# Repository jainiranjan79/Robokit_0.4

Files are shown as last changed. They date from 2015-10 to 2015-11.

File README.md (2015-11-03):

# scratchduino-RoboKit v0.4
This repository includes **body, schematics, PCB, documentation and sources** for RoboKit v0.4

#Directories
* Body - *the body of roboplatform and sensors*
* Documentation - *the .pdf schematics, etc*
* Firmware - *the firmware for RoboKit v0.4*
* PCB - *Printed Circuit Boards for Roboplatform and sensors*
    * Gerber - *gerber files + gerber drill files*
        * Cartridge
        * ...
    * SVG - *svg files without drill files*
        * Cartridge
        * ...
* Sources - *the sources for PCB and Body*
    * Cartridge - *Kicad files for PCB*
        * make - *This bash script distribute Gerber, SVG and PDF files to directories PCB,Documentation*
        * PCB - *Here you need print PCB in svg and gerber formats( read make )*
    * ...

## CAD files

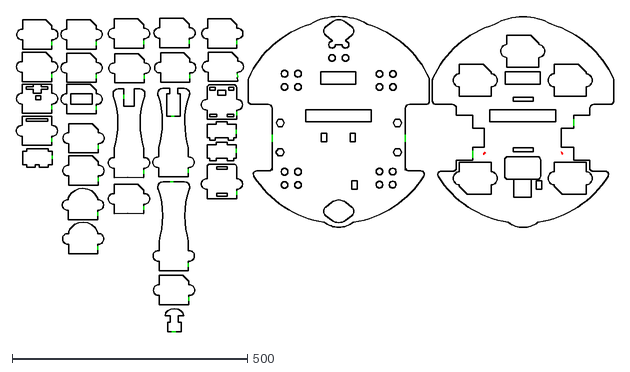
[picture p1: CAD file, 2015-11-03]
Body/2mm.dxf
1270.6 x 670.4

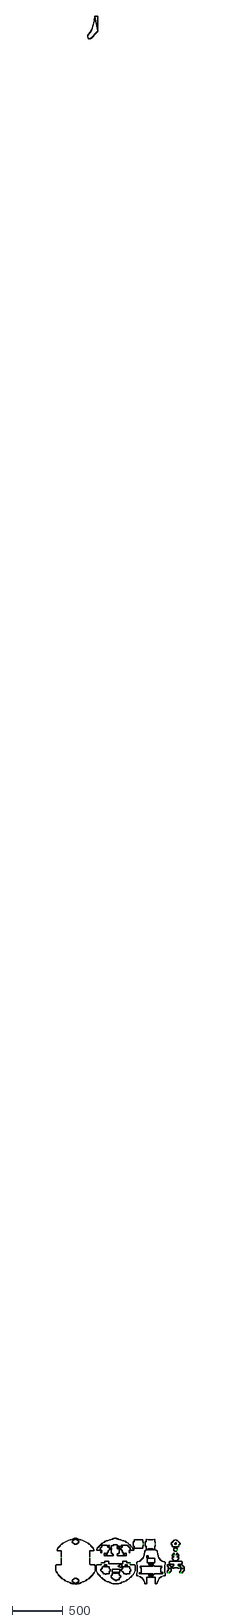
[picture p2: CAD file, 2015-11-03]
Body/3mm.dxf
1260.2 x 15413.3

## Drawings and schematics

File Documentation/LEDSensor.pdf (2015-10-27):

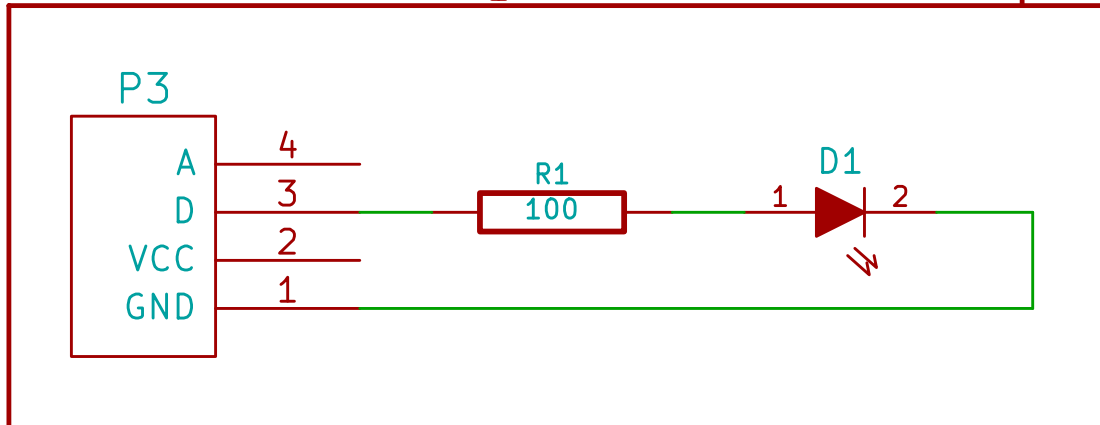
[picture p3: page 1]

Id: 1/1 Title: noname.sch File: LEDSensor.sch
Sheet: /

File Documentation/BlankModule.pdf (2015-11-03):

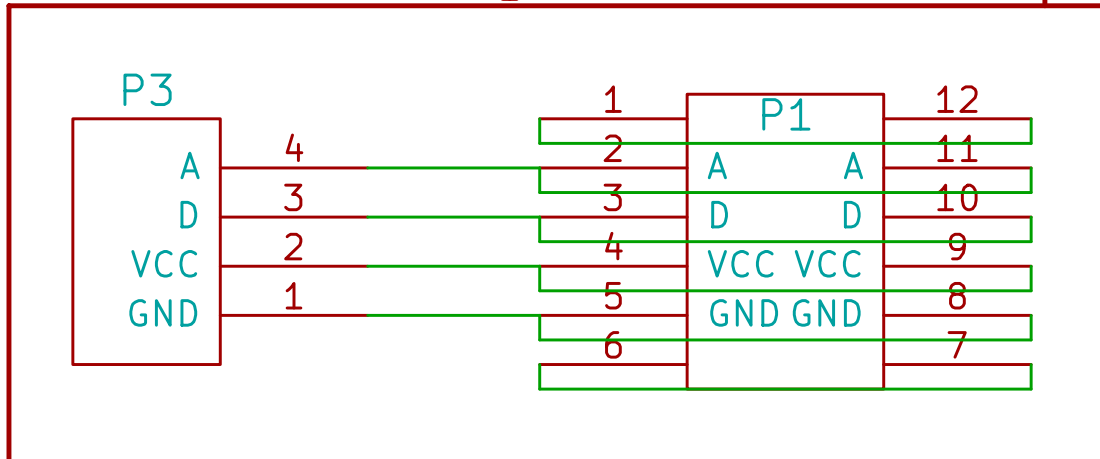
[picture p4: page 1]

Id: 1/1 Title: noname.sch File: BlankModule.sch Sheet: /

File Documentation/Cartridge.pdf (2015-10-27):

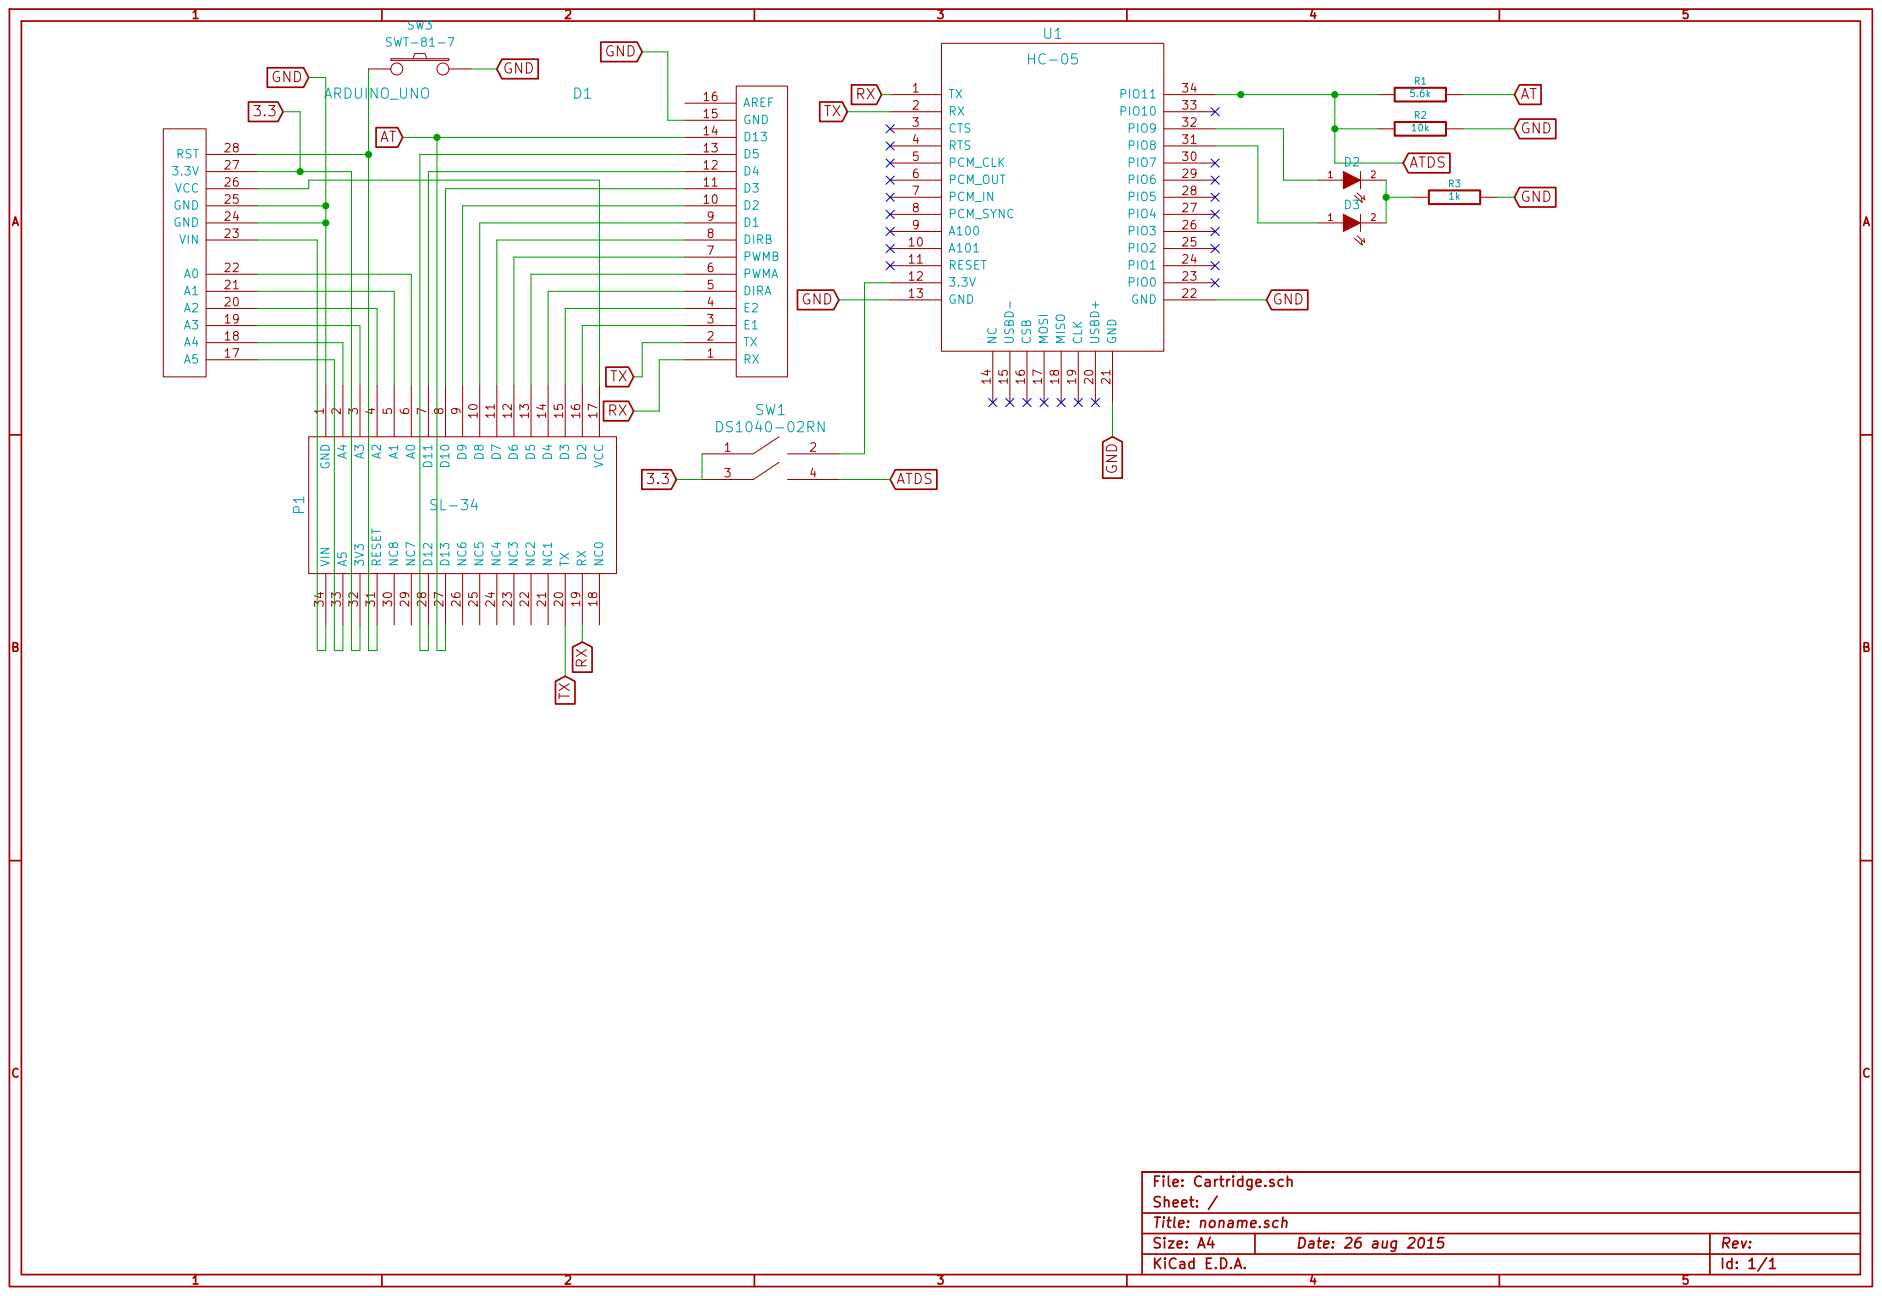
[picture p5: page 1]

9 D8 10 TX 20 NC8 30 D7 11 NC1 21 RESET 31 D6 12 NC2 22 3V3 32 D5 13 NC3 23 A5 33 D4 14 NC4 24 VIN 34 D3 15 NC5 25 D2 16 NC6 26 VCC 17 D13 27 NC0 18 D12 28 RX 19 NC7 29 P1SL-34

Id: 1/1 Title: noname.sch File: Cartridge.sch

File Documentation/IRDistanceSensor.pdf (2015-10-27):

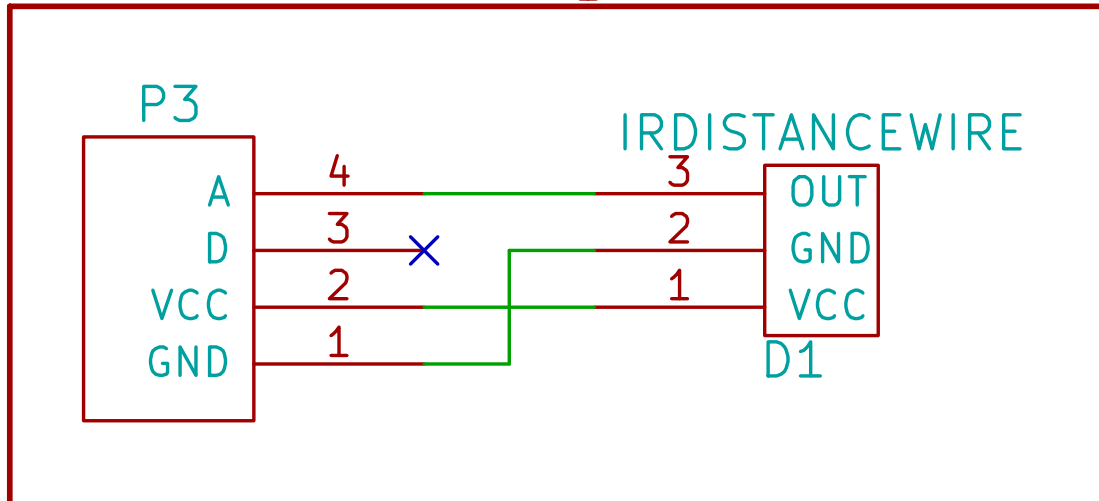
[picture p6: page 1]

Id: 1/1 Title: noname.sch File: IRDistanceSensor.sch
Sheet: /

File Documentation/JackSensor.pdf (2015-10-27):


Id: 1/1 Title: noname.sch File: JackSensor.sch
Sheet: /

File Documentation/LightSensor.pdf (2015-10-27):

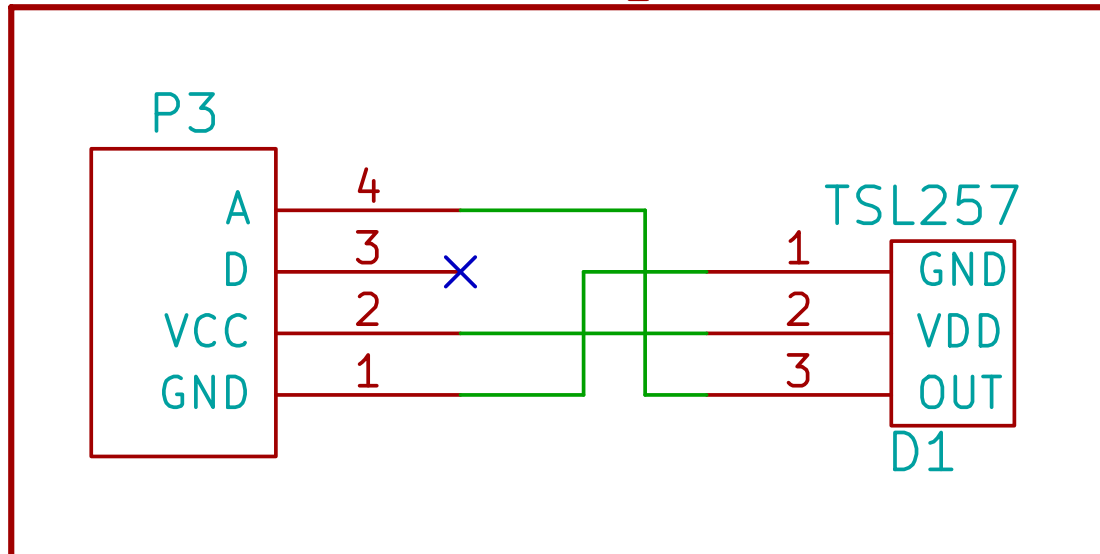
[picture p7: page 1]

Id: 1/1 Title: noname.sch File: LightSensor.sch
Sheet: /

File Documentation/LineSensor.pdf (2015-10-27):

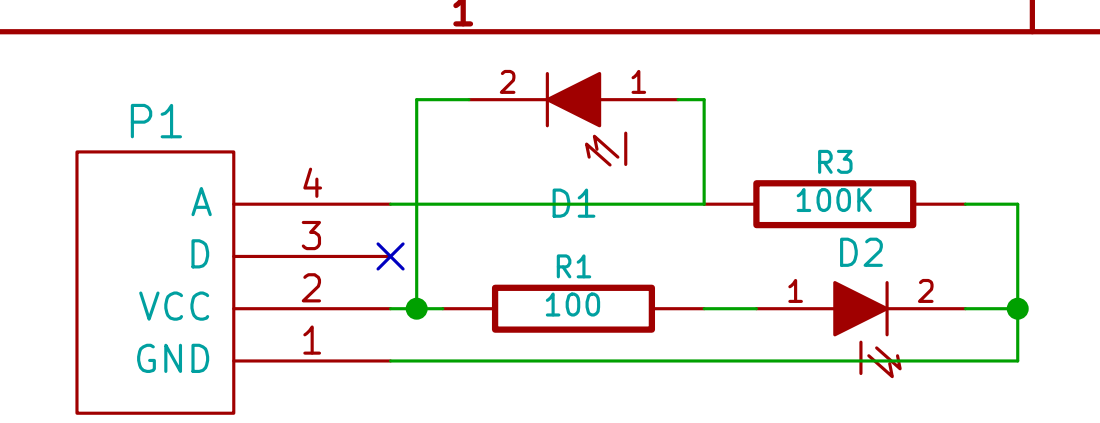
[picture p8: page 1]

Id: 1/1 Title: noname.sch File: LineSensor.sch
Sheet: /

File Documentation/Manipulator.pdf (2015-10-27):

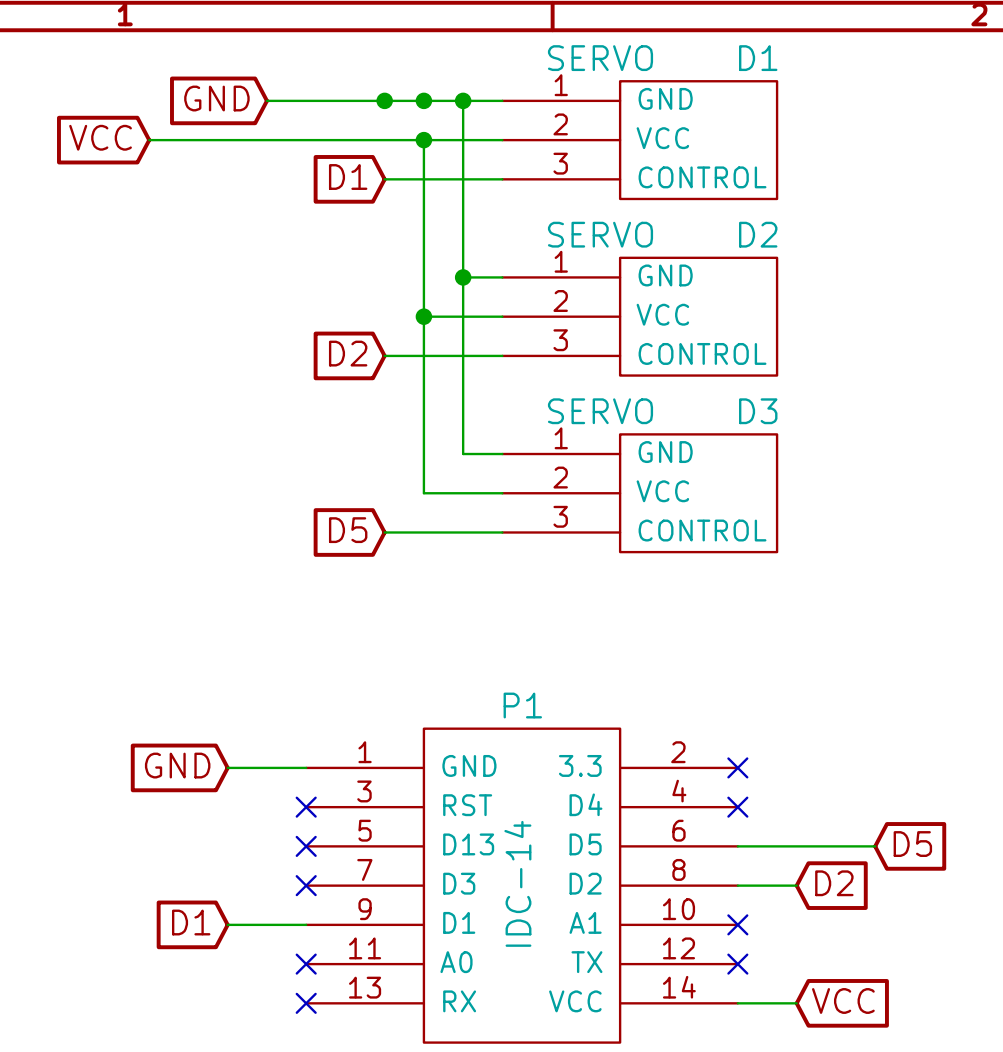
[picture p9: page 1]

Id: 1/1 Title: File: Manipulator.sch
Sheet: /

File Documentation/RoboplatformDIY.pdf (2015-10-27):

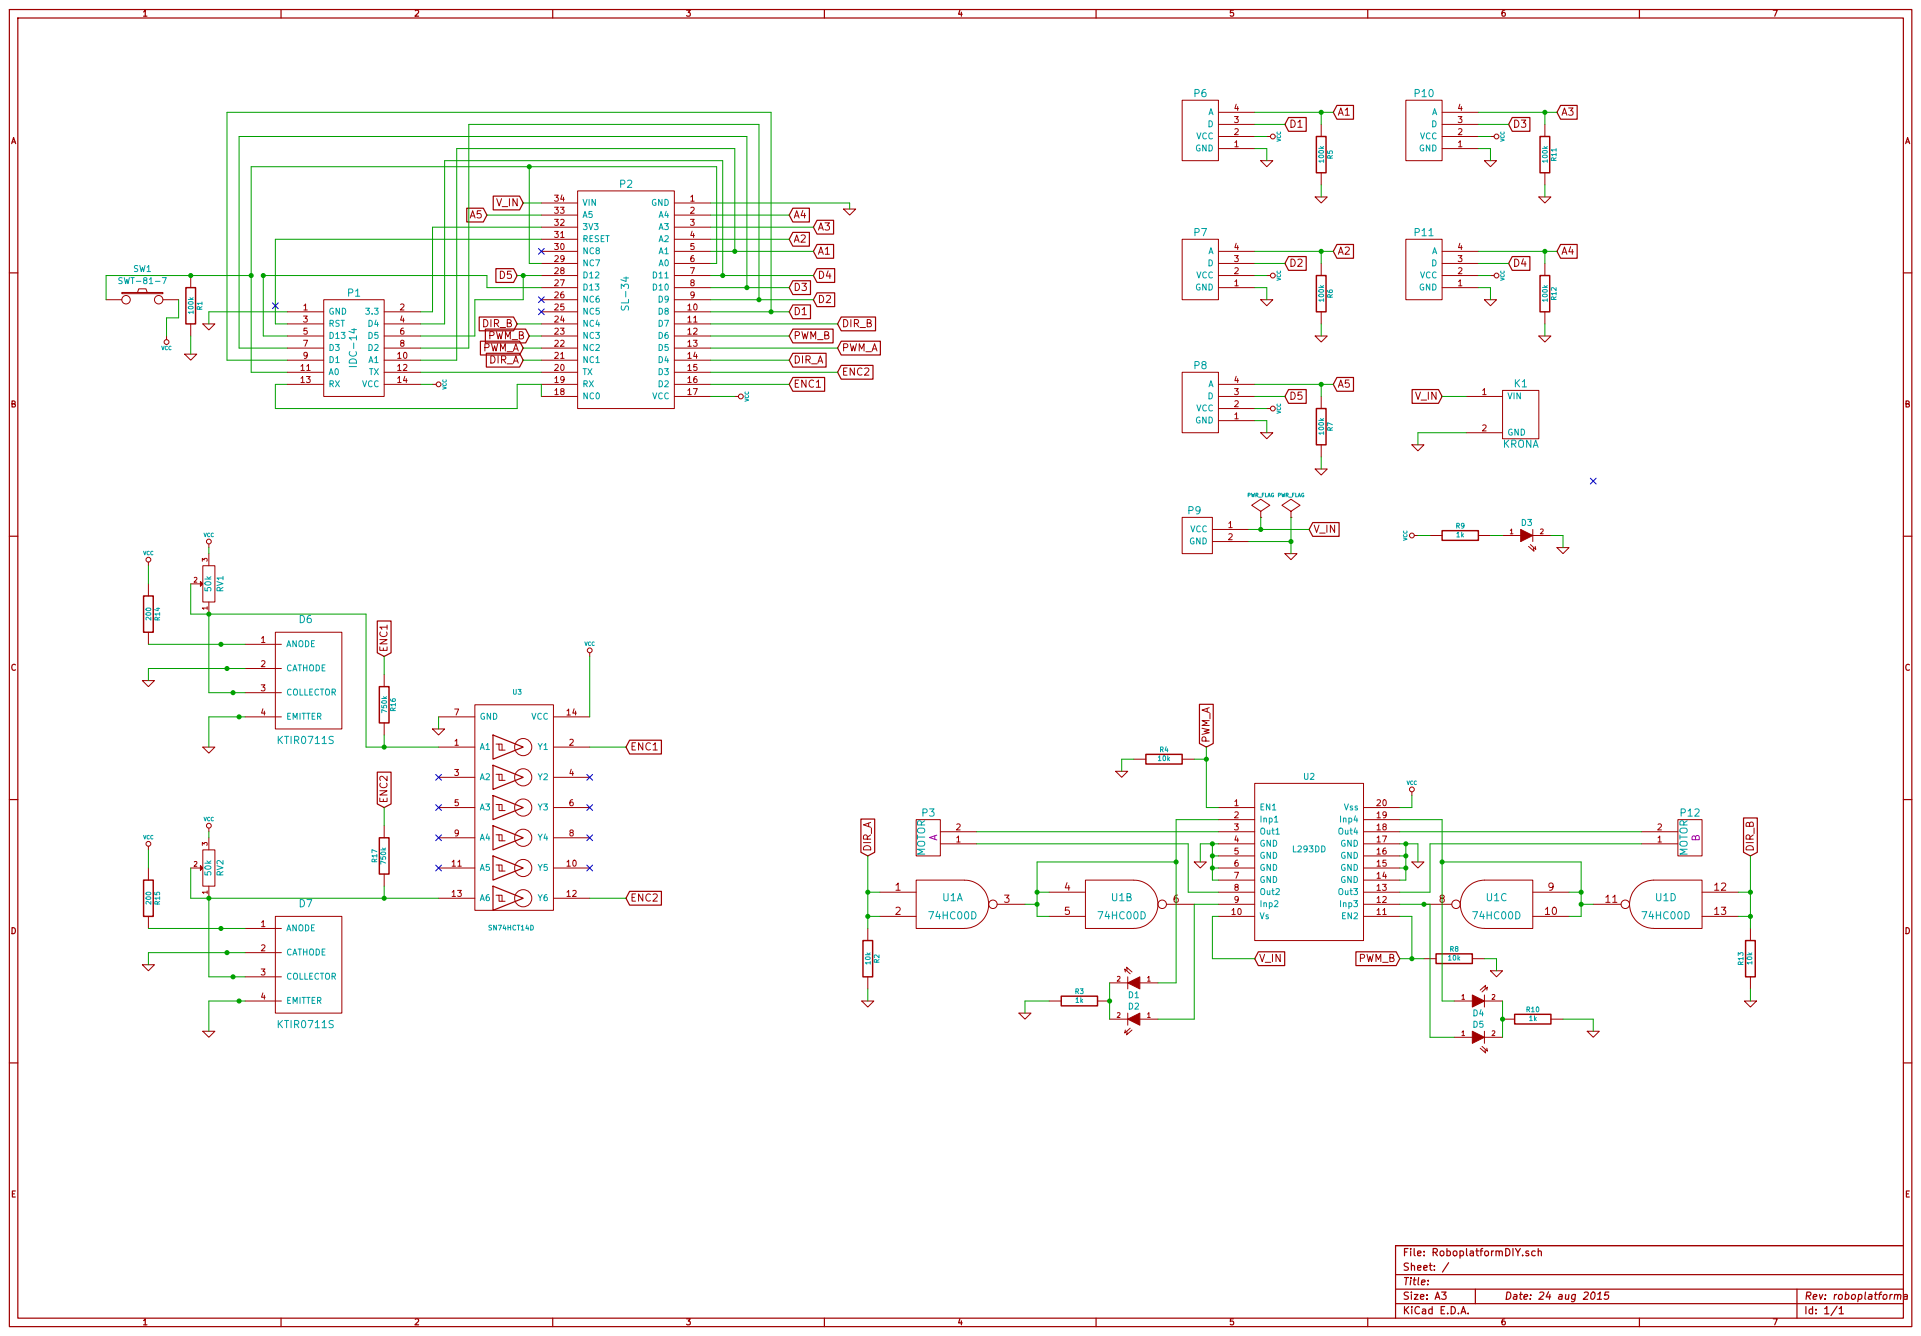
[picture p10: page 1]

Id: 1/1 Title: File: RoboplatformDIY.sch

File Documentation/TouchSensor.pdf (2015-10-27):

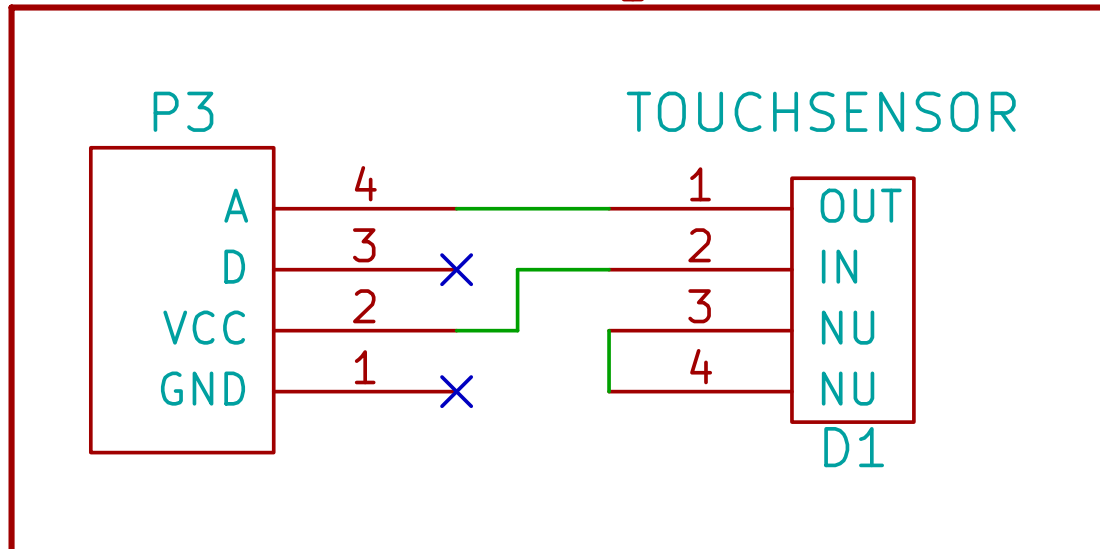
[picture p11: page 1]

Id: 1/1 Title: noname.sch File: TouchSensor.sch
Sheet: /

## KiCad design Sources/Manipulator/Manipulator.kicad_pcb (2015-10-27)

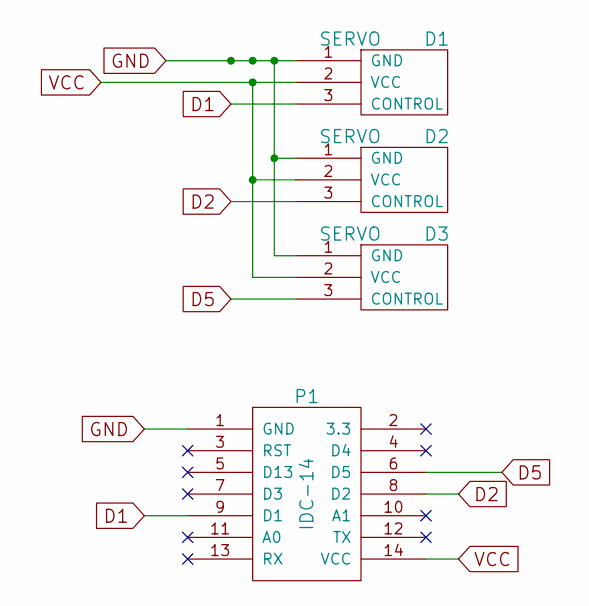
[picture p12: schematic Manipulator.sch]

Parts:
D1, D2, D3: SERVO
P1: IDC-14

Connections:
D1: D1.3 (CONTROL), P1.9 (D1)
D2: D2.3 (CONTROL), P1.8 (D2)
D5: D3.3 (CONTROL), P1.6 (D5)
GND: D1.1 (GND), D2.1 (GND), D3.1 (GND), P1.1 (GND)
VCC: D1.2 (VCC), D2.2 (VCC), D3.2 (VCC), P1.14 (VCC)

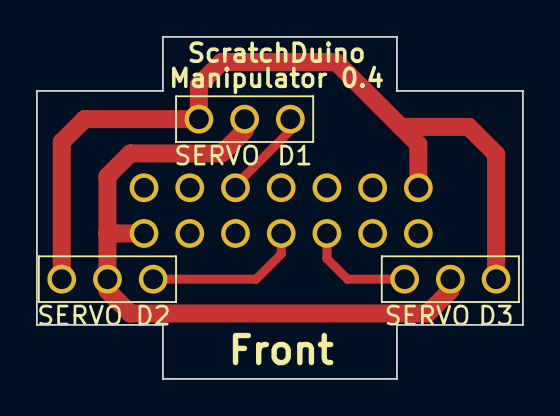
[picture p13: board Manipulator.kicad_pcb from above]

Board: 2 copper layers, 27.0 x 19.0 mm, 4 parts (1 on the bottom side), 5 nets.

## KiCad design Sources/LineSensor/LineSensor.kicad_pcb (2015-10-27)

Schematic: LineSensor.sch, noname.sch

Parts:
D1: INFAREDPHOTODIODE
D2: INFAREDLED
P1: SENSOR
R1: 100
R3: 100K

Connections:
unnamed: D1.1, P1.4 (A), R3.1
unnamed: D1.2, P1.2 (VCC), R1.1
unnamed: D2.2, P1.1 (GND), R3.2
unnamed: D2.1, R1.2

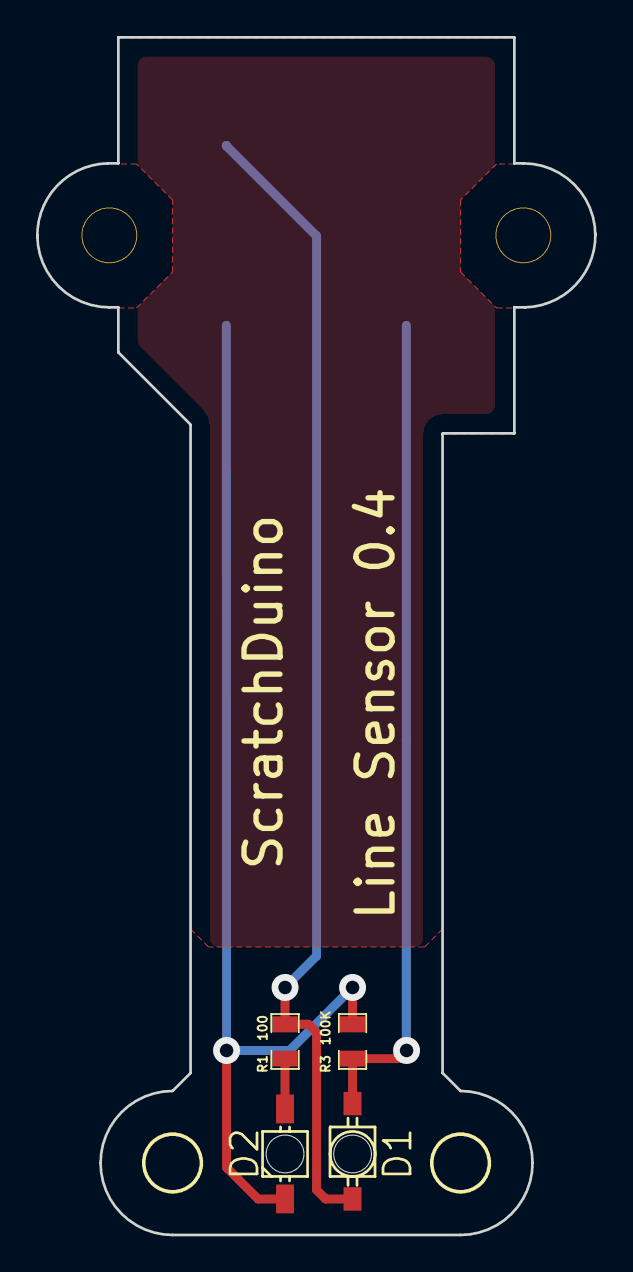
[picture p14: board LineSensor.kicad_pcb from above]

Board: 2 copper layers, 31.0 x 66.5 mm, 5 parts (1 on the bottom side), 4 nets.

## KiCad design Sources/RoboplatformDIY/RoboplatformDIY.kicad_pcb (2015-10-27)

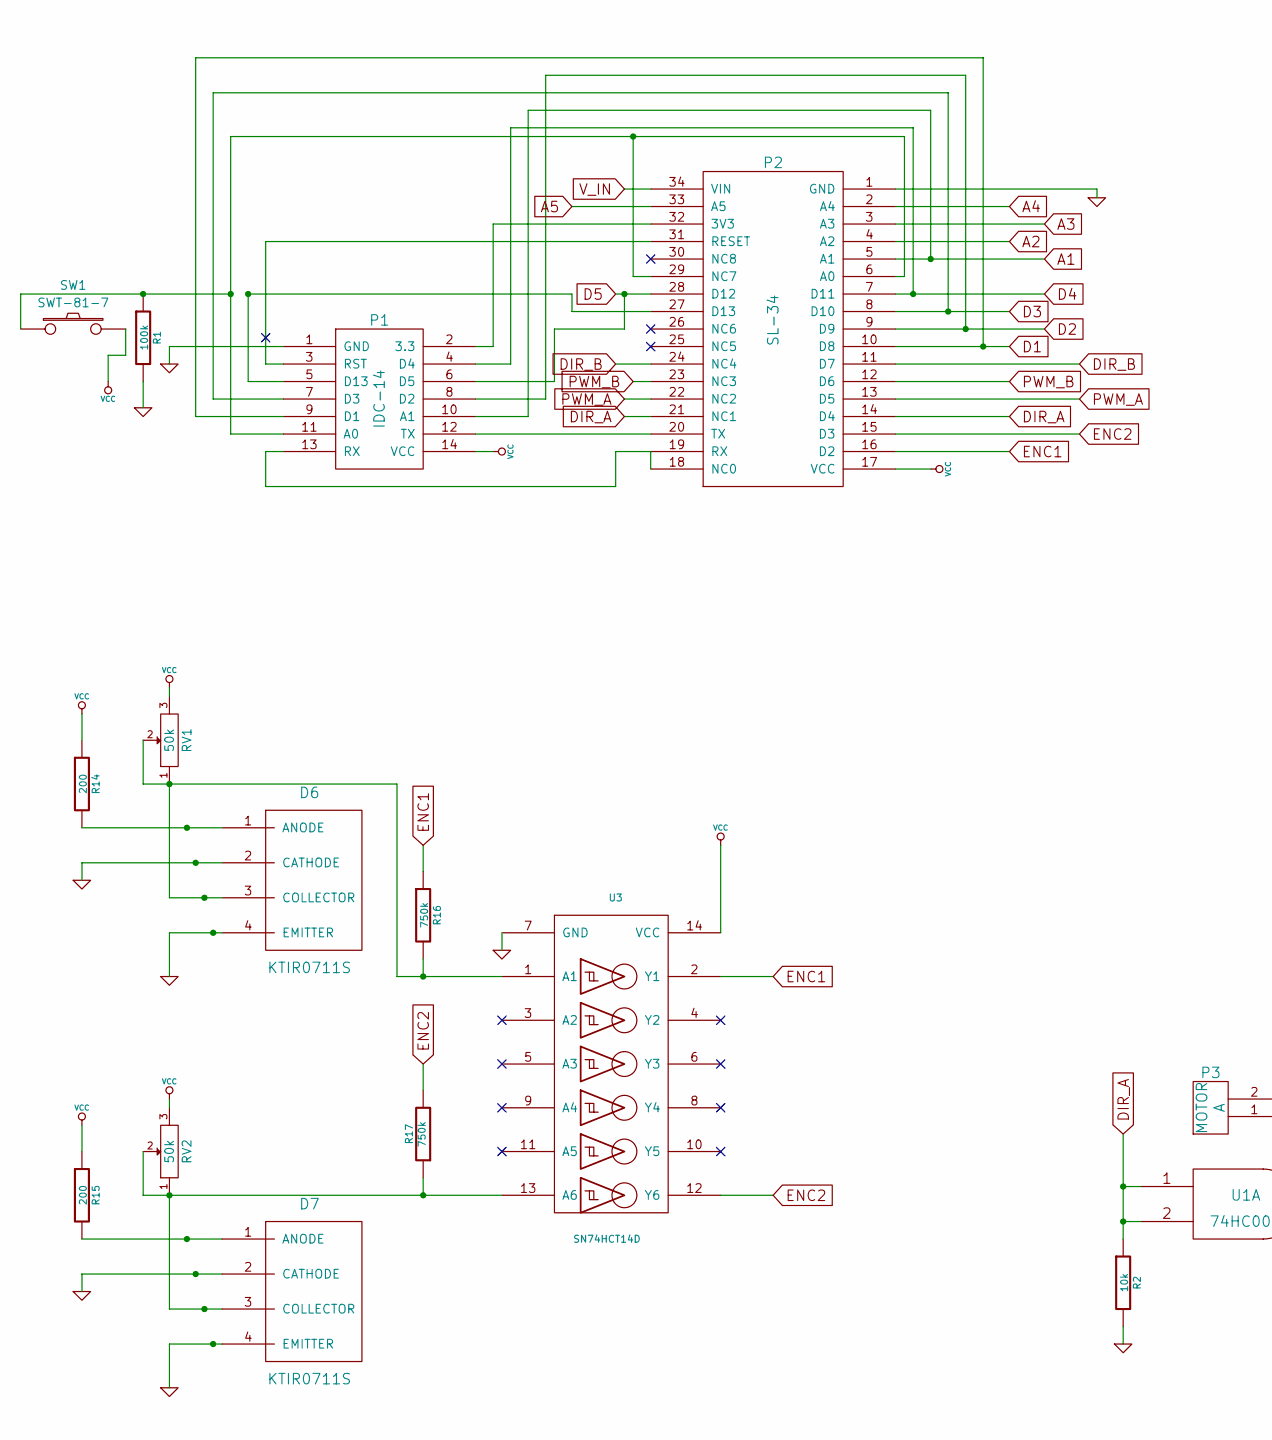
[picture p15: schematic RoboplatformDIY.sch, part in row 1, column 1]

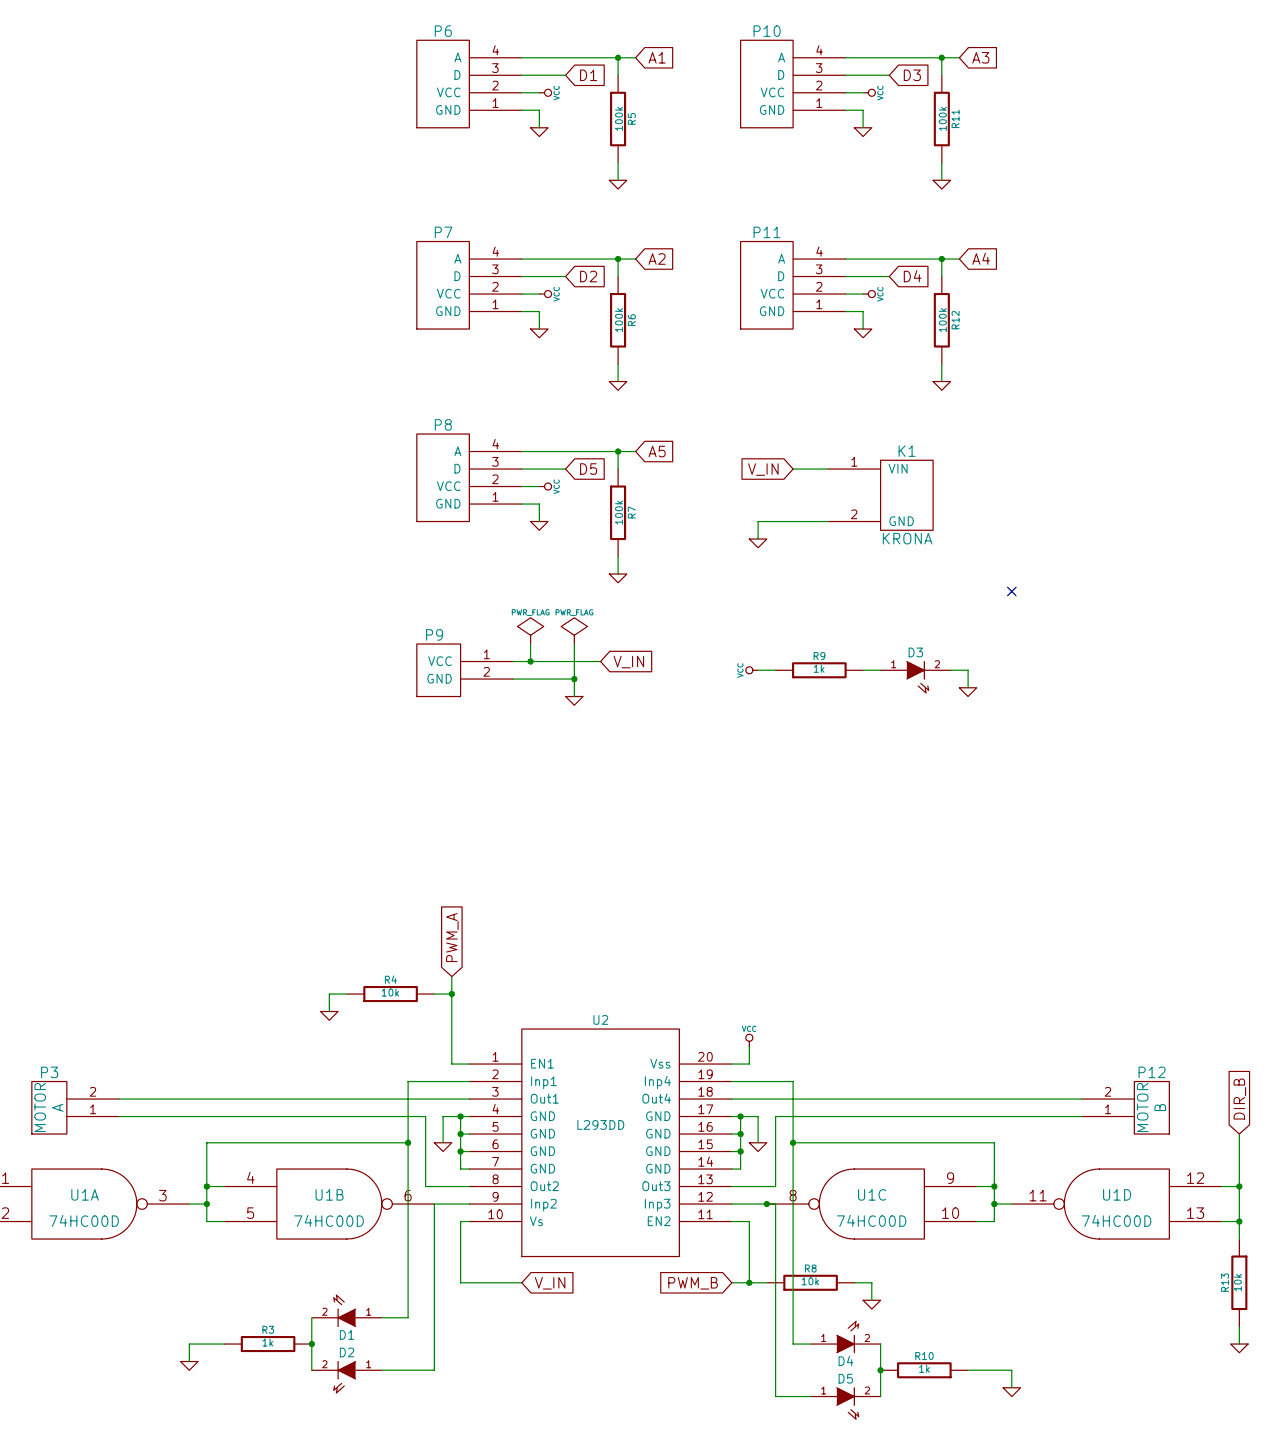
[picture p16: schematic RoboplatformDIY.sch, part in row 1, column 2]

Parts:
D1, D2, D3, D4, D5: LED
D6, D7: KTIR0711S
K1: KRONA
P1: IDC-14
P2: SL-34
P3, P12: MOTOR
P6, P7, P8, P10: SENSOR
P9: POWER
P11: SENSOR
R1, R5, R6, R7, R11, R12: 100k
R2, R4, R8, R13: 10k
R3, R9, R10: 1k
R14, R15: 200
R16, R17: 750k
RV1, RV2: 50k
SW1: SWT-81-7
U1: 74HC00D
U2: L293DD; MODULE
U3: SN74HCT14D

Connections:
A1: P1.10 (A1), P2.5 (A1), P6.4 (A), R5.1
A2: P2.4 (A2), P7.4 (A), R6.1
A3: P2.3 (A3), P10.4 (A), R11.1
A4: P2.2 (A4), P11.4 (A), R12.1
A5: P2.33 (A5), P8.4 (A), R7.1
D1: P1.9 (D1), P2.10 (D8), P6.3 (D)
D2: P1.8 (D2), P2.9 (D9), P7.3 (D)
D3: P1.7 (D3), P2.8 (D10), P10.3 (D)
D4: P1.4 (D4), P2.7 (D11), P11.3 (D)
D5: P1.6 (D5), P2.28 (D12), P8.3 (D)
DIR_A: P2.14 (D4), P2.21 (NC1), R2.1, U1.1, U1.2
DIR_B: P2.11 (D7), P2.24 (NC4), R13.1, U1.12, U1.13
ENC1: P2.16 (D2), R16.1, U3.2 (Y1)
ENC2: P2.15 (D3), R17.2, U3.12 (Y6)
GND: D3.2 (K), D6.2 (CATHODE), D6.4 (EMITTER), D7.2 (CATHODE), D7.4 (EMITTER), K1.2 (GND), P1.1 (GND), P2.1 (GND), P6.1 (GND), P7.1 (GND), P8.1 (GND), P9.2 (GND), P10.1 (GND), P11.1 (GND), R1.2, R2.2, R3.1, R4.1, R5.2, R6.2, R7.2, R8.2, R10.1, R11.2, R12.2, R13.2, U1.7 (GND), U2.4 (GND), U2.5 (GND), U2.6 (GND), U2.7 (GND), U2.14 (GND), U2.15 (GND), U2.16 (GND), U2.17 (GND), U3.7 (GND)
unnamed: P1.12 (TX), P2.20 (TX)
unnamed: P1.13 (RX), P2.18 (NC0), P2.19 (RX)
unnamed: P1.3 (RST), P2.31 (RESET)
unnamed: P1.2 (3.3), P2.32 (3V3)
unnamed: P3.2, U2.3 (Out1)
unnamed: P1.11 (A0), P2.6 (A0), P2.29 (NC7), R1.1, SW1.1
unnamed: P3.1, U2.8 (Out2)
unnamed: D1.1 (A), U1.3, U1.4, U1.5, U2.2 (Inp1)
unnamed: P12.1, U2.13 (Out3)
unnamed: P12.2, U2.18 (Out4)
unnamed: D4.1 (A), U1.9, U1.10, U1.11, U2.19 (Inp4)
unnamed: D7.1 (ANODE), R15.2
unnamed: D6.1 (ANODE), R14.2
unnamed: D2.1 (A), U1.6, U2.9 (Inp2)
unnamed: P1.5 (D13), P2.27 (D13)
unnamed: D3.1 (A), R9.2
unnamed: D7.3 (COLLECTOR), R17.1, RV2.1, RV2.2, U3.13 (A6)
unnamed: D6.3 (COLLECTOR), R16.2, RV1.1, RV1.2, U3.1 (A1)
unnamed: D1.2 (K), D2.2 (K), R3.2
unnamed: D4.2 (K), D5.2 (K), R10.2
unnamed: D5.1 (A), U1.8, U2.12 (Inp3)
PWM_A: P2.13 (D5), P2.22 (NC2), R4.2, U2.1 (EN1)
PWM_B: P2.12 (D6), P2.23 (NC3), R8.1, U2.11 (EN2)
VCC: P1.14 (VCC), P2.17 (VCC), P6.2 (VCC), P7.2 (VCC), P8.2 (VCC), P10.2 (VCC), P11.2 (VCC), R9.1, R14.1, R15.1, RV1.3, RV2.3, SW1.2, U1.14 (VCC), U2.20 (Vss), U3.14 (VCC)
V_IN: K1.1 (VIN), P2.34 (VIN), P9.1 (VCC), U2.10 (Vs)

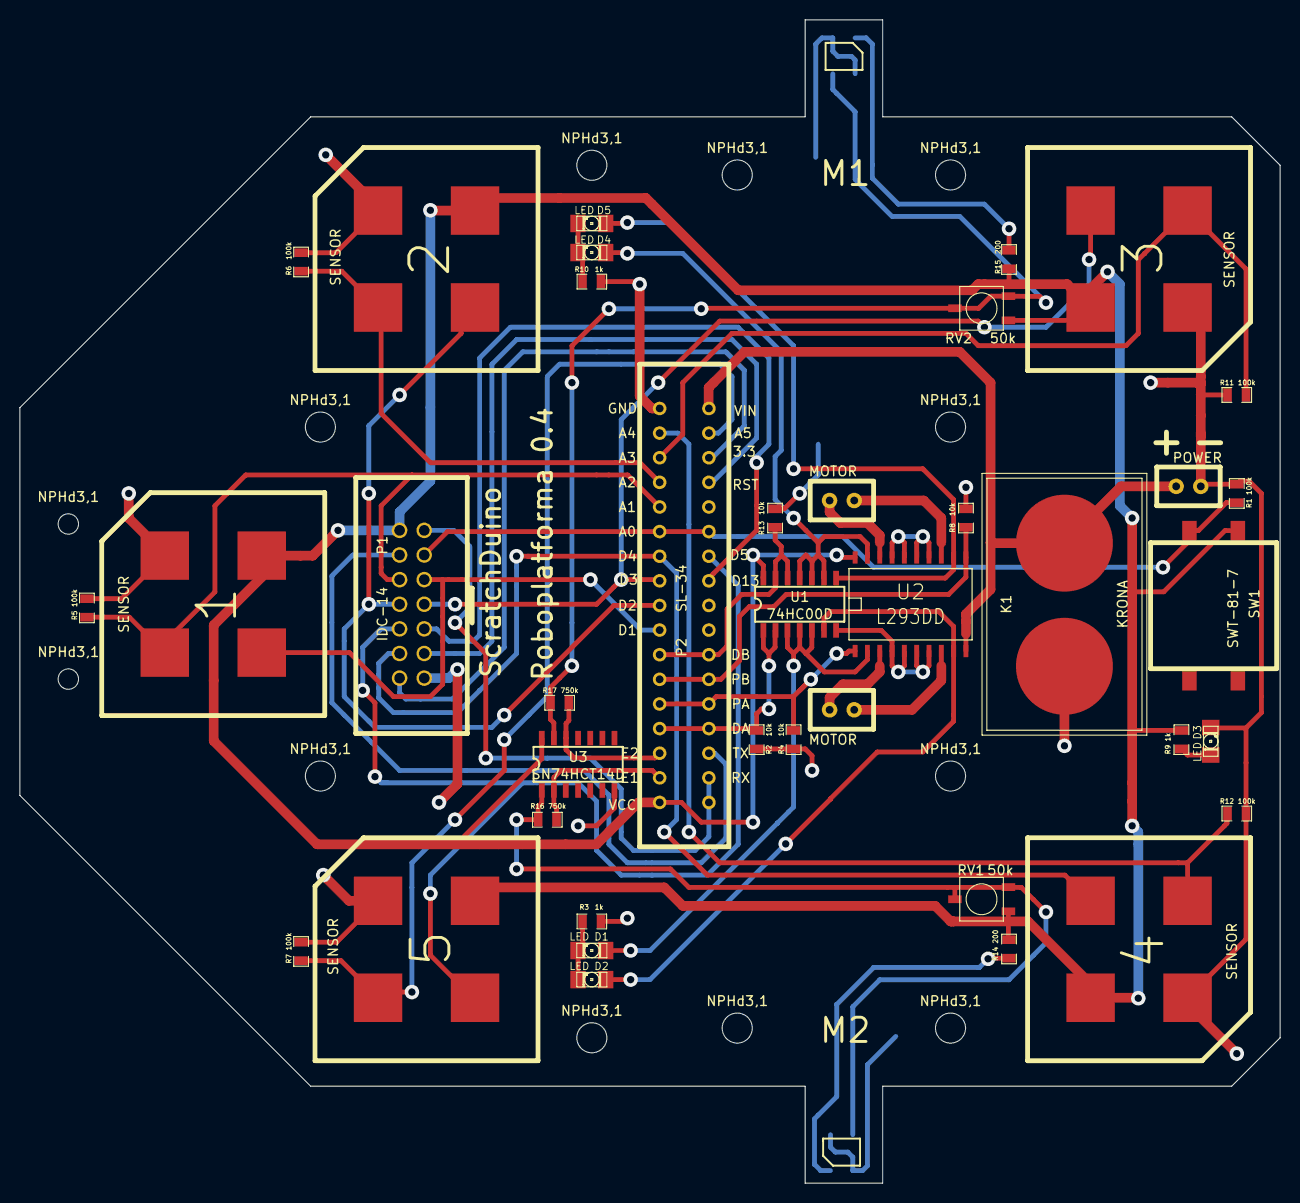
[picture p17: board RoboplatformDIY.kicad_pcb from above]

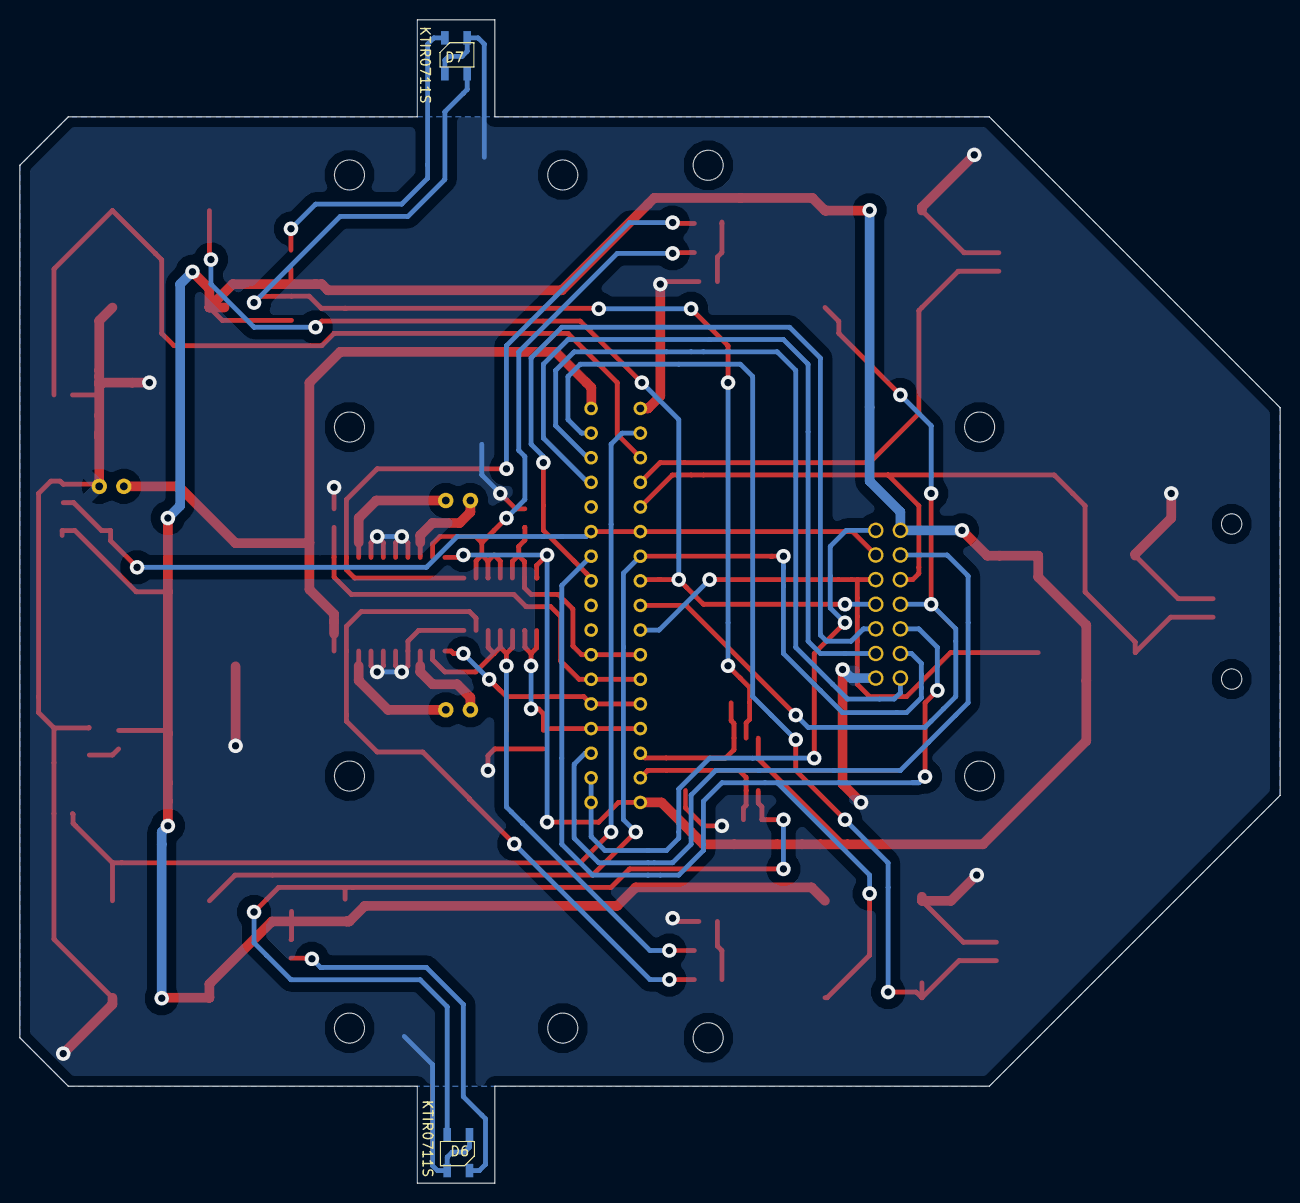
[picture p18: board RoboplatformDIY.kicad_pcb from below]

Board: 2 copper layers, 130.0 x 120.0 mm, 53 parts (2 on the bottom side), 40 nets.

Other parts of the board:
NPHd3,1, NPHd3,1#2, NPHd3,1#3, NPHd3,1#4, NPHd3,1#5, NPHd3,1#6, NPHd3,1#7, NPHd3,1#8, NPHd3,1#9, NPHd3,1#10: NPHd3,1
NPHd3,1#11, NPHd3,1#12: NPHd2,1

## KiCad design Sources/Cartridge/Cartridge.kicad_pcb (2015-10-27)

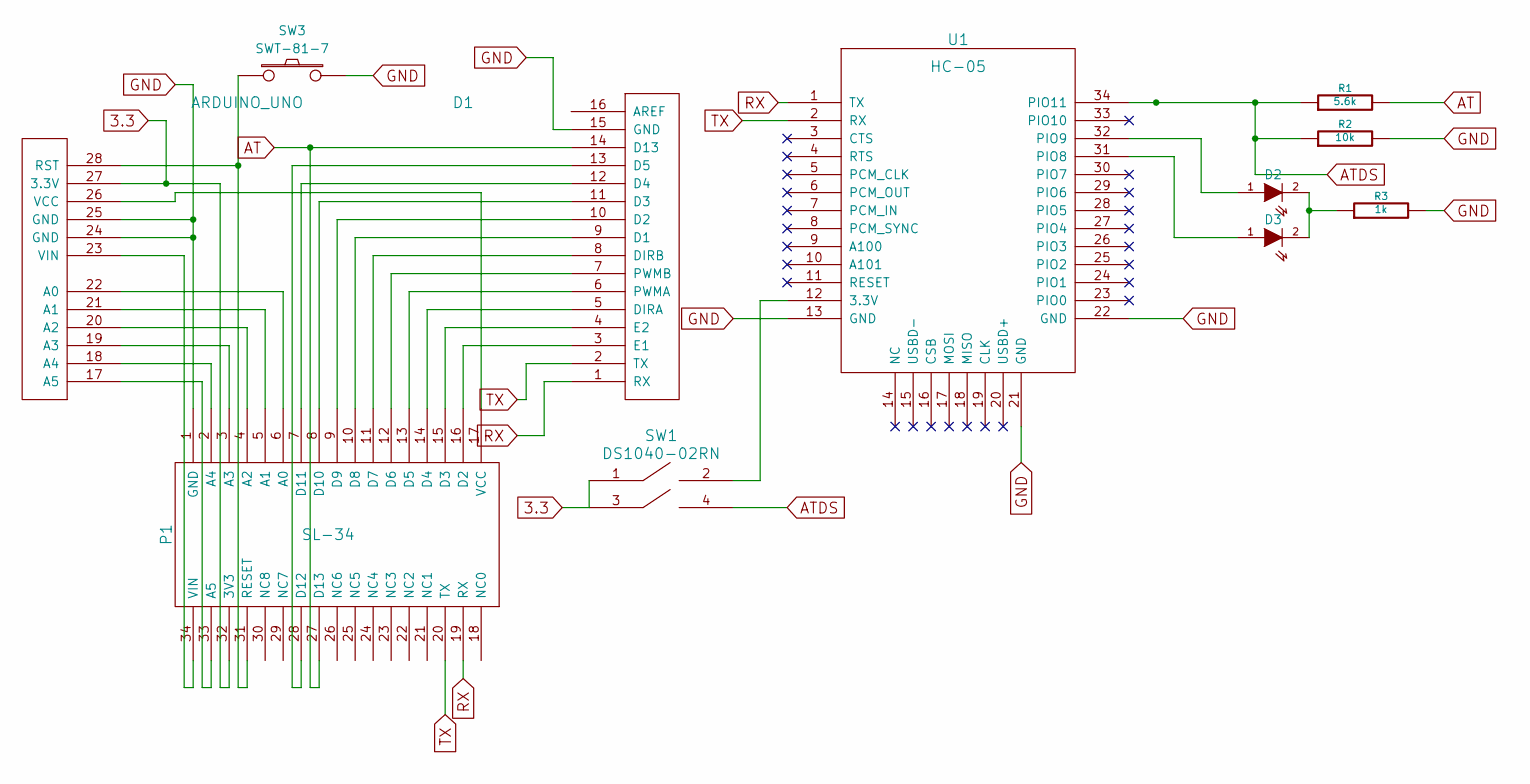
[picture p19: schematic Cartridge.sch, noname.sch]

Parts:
D1: ARDUINO_UNO
D2, D3: LED
P1: SL-34
R1: 5.6k
R2: 10k
R3: 1k
SW1: DS1040-02RN
SW3: SWT-81-7
U1: HC-05

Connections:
3.3: D1.27 (3.3V), P1.32 (3V3), SW1.1, SW1.3
AT: D1.14 (D13), P1.27 (D13), R1.2
ATDS: R1.1, R2.1, SW1.4, U1.34 (PIO11)
GND: D1.15 (GND), D1.24 (GND), D1.25 (GND), P1.1 (GND), R2.2, R3.2, SW3.2, U1.13 (GND), U1.21 (GND), U1.22 (GND)
unnamed: D1.17 (A5), P1.33 (A5)
unnamed: D1.28 (RST), P1.31 (RESET), SW3.1
unnamed: D1.3 (E1), P1.16 (D2)
unnamed: D1.4 (E2), P1.15 (D3)
unnamed: D1.5 (DIRA), P1.14 (D4)
unnamed: D1.26 (VCC), P1.17 (VCC)
unnamed: D1.23 (VIN), P1.34 (VIN)
unnamed: D1.21 (A1), P1.5 (A1)
unnamed: D1.11 (D3), P1.8 (D10)
unnamed: D1.10 (D2), P1.9 (D9)
unnamed: D1.9 (D1), P1.10 (D8)
unnamed: D1.22 (A0), P1.6 (A0)
unnamed: D1.12 (D4), P1.7 (D11)
unnamed: D1.20 (A2), P1.4 (A2)
unnamed: D1.19 (A3), P1.3 (A3)
unnamed: D1.18 (A4), P1.2 (A4)
unnamed: D1.13 (D5), P1.28 (D12)
unnamed: D1.8 (DIRB), P1.11 (D7)
unnamed: D1.7 (PWMB), P1.12 (D6)
unnamed: D1.6 (PWMA), P1.13 (D5)
unnamed: D2.2 (K), D3.2 (K), R3.1
unnamed: D3.1 (A), U1.31 (PIO8)
unnamed: SW1.2, U1.12 (3.3V)
unnamed: D2.1 (A), U1.32 (PIO9)
RX: D1.1 (RX), P1.19 (RX), U1.1 (TX)
TX: D1.2 (TX), P1.20 (TX), U1.2 (RX)

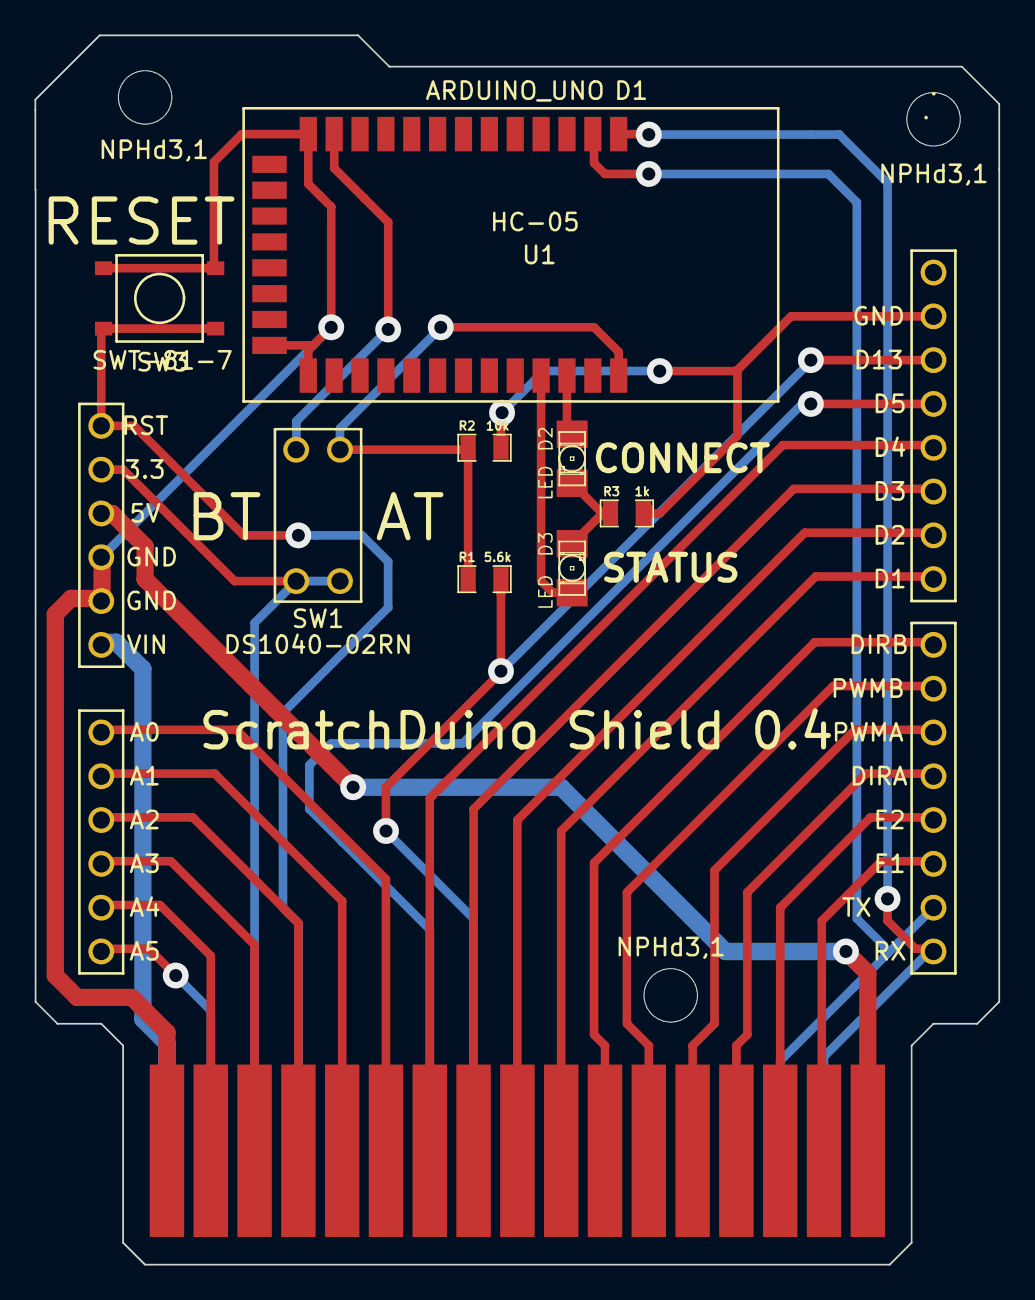
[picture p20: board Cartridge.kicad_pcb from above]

Board: 2 copper layers, 55.9 x 71.3 mm, 13 parts (1 on the bottom side), 30 nets.

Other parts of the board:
NPHd3,1, NPHd3,1#2, NPHd3,1#3: NPHd3,1

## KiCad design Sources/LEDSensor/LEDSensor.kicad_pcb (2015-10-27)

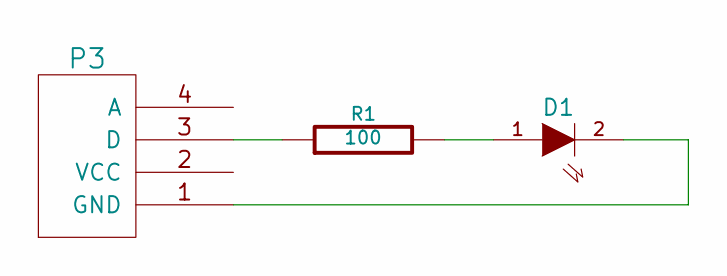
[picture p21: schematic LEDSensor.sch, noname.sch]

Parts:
D1: LED
P3: SENSOR
R1: 100

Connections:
unnamed: P3.3 (D), R1.1
unnamed: D1.1 (A), R1.2
unnamed: D1.2 (K), P3.1 (GND)

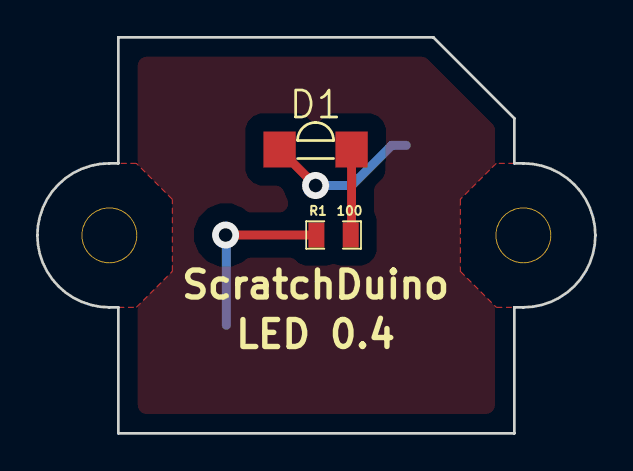
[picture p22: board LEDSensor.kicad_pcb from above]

Board: 2 copper layers, 31.0 x 22.0 mm, 3 parts (1 on the bottom side), 3 nets.

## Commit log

2015-10-27 PCB and sources
    [Cartridge.kicad_pcb, Cartridge.sch, IRDistanceSensor.kicad_pcb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]
2015-11-03 Body has been added
    [2mm.dxf, 3mm.dxf, BlankModule.kicad_pcb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]
2015-11-03 new IR Distance Sensor
    [IRDistanceSensor.kicad_pcb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]
